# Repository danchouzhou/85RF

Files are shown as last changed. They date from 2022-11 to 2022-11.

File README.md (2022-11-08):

# 85RF
A 2.4G remote control made with ATtiny85
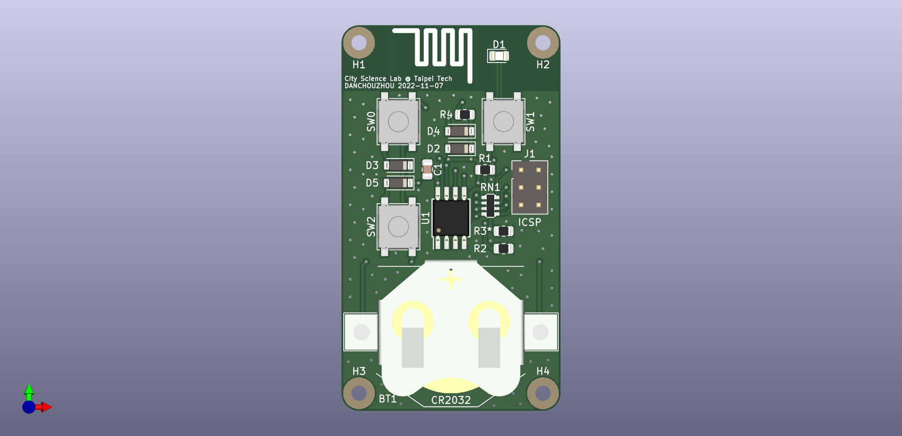
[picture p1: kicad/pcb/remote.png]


## Fetures
- ATtiny85 compatible with Arduino IDE
- nRF24L01+ / Si24R1 2.4G transceiver
- Zero quiescent current design
- Single CR2032 battery power, select one side to place the battery holder
- Onboard 6-pin AVR-ISP header for developing and re-programming

## Arduino IDE setup
### Board manager
Check out the [installation guide of ATTinyCore](https://github.com/SpenceKonde/ATTinyCore/blob/v2.0.0-devThis-is-the-head-submit-PRs-against-this/Installation.md) by Spence Konde (aka Dr. Azzy)

### Library
This project uses [RF24](https://github.com/nRF24/RF24) by 2bndy5, it's a famous library of nRF24L01. It is possible to install the library directly from the library manager.

## Datasheet
- [Atmel ATtiny25, ATtiny45, ATtiny85 Datasheet](https://ww1.microchip.com/downloads/en/DeviceDoc/Atmel-2586-AVR-8-bit-Microcontroller-ATtiny25-ATtiny45-ATtiny85_Datasheet.pdf)
- [nRF24L01P_PS_v1.0.pdf - Nordic Semiconductor](https://infocenter.nordicsemi.com/pdf/nRF24L01P_PS_v1.0.pdf)
- [Ai-thinker NF-03 Specification](https://docs.ai-thinker.com/_media/nf-03_specification_en.pdf)

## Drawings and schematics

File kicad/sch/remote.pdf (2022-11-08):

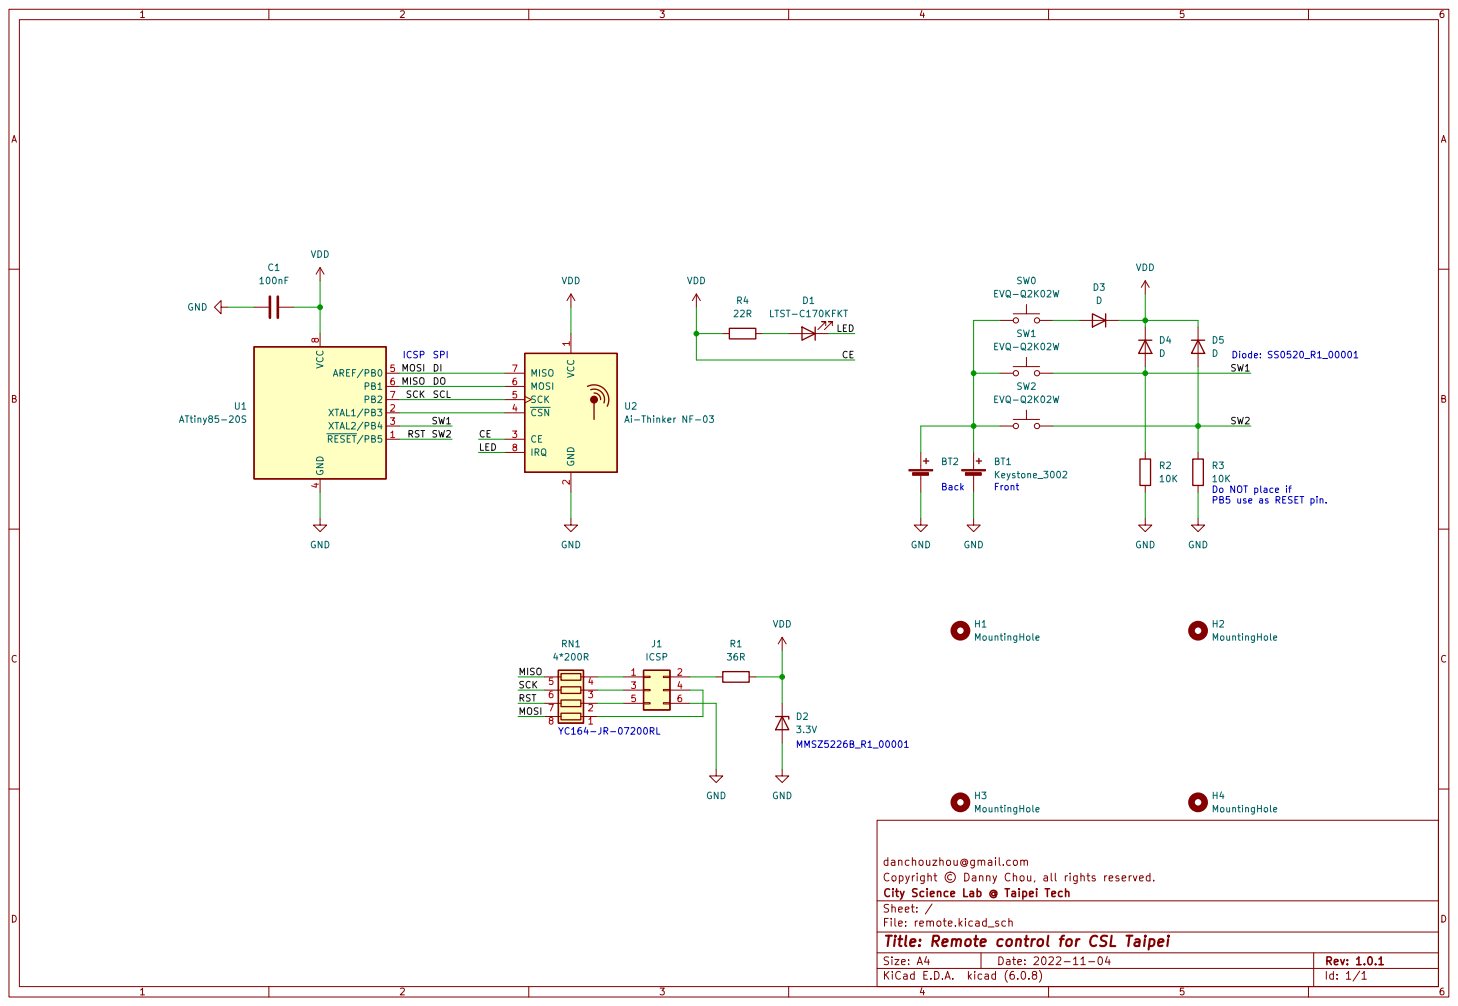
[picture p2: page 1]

2 CE 3 ~{CSN} 4 SCK 5 MOSI 6 MISO 7

danchouzhou@gmail.com
File: remote.kicad_sch Sheet: / City Science Lab @ Taipei Tech

Id: 1/1 Title: Remote control for CSL Taipei

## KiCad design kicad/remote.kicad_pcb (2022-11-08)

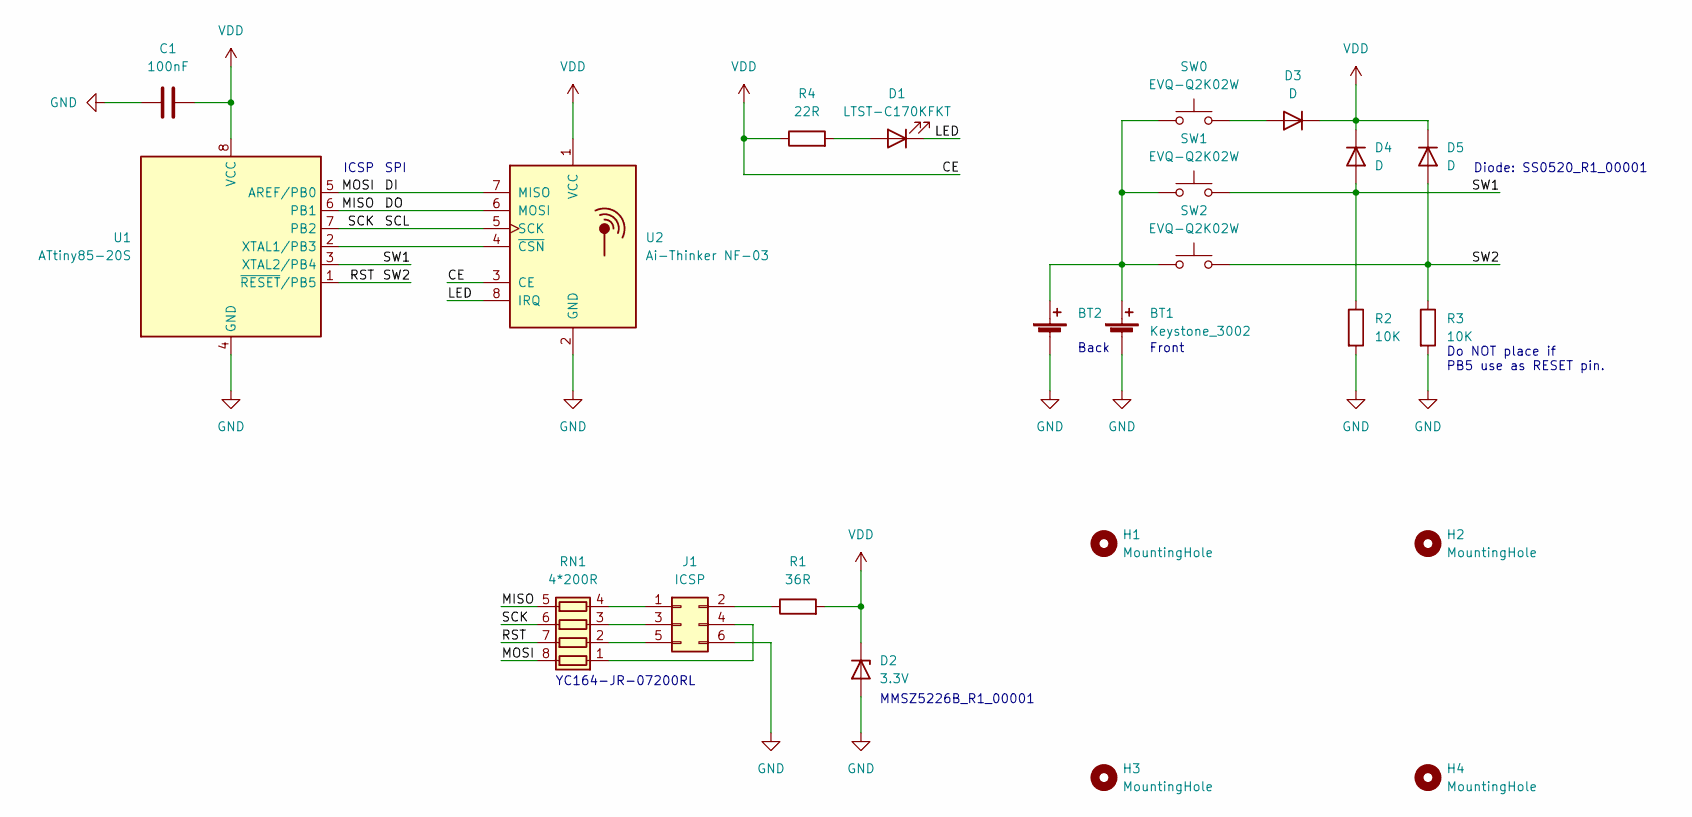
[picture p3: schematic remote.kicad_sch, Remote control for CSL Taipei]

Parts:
BT1: Keystone_3002; BatteryHolder_Keystone_3002_1x2032
BT2: BatteryHolder_Keystone_3002_1x2032
C1: 100nF; C_0805_2012Metric
D1: LTST-C170KFKT; LED_0805_2012Metric
D2: 3.3V; D_SOD-123
D3, D4, D5: D; D_SOD-123
H1, H2, H3, H4: MountingHole; MountingHole_2.2mm_M2
J1: ICSP; PinHeader_2x03_P2.54mm_Vertical
R1: 36R; R_0805_2012Metric
R2, R3: 10K; R_0805_2012Metric
R4: 22R; R_0805_2012Metric
RN1: 4*200R; R_Array_Convex_4x0603
SW0, SW1, SW2: EVQ-Q2K02W; SW_SPST_EVQP0
U1: ATtiny85-20S; SOIC-8W_5.3x5.3mm_P1.27mm
U2: Ai-Thinker NF-03; Ai-Thinker-NF-03

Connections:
/DI: RN1.8 (R1.2), U1.5 (AREF/PB0), U2.7 (MISO)
/DO: RN1.5 (R4.2), U1.6 (PB1), U2.6 (MOSI)
/LED: D1.1 (K), U2.8 (IRQ)
/RST: D5.2 (A), R3.1, RN1.7 (R2.2), SW2.2, U1.1 (~RESET/PB5); also elsewhere on the board
/SCK: RN1.6 (R3.2), U1.7 (PB2), U2.5 (SCK)
/SW1: D4.2 (A), R2.1, SW1.2, U1.3 (XTAL2/PB4)
GND: BT1.2 (-), BT2.2 (-), C1.1, D2.2 (A), J1.6, R2.2, R3.2, U1.4 (GND), U2.2 (GND); also elsewhere on the board
unnamed: BT1.1 (+), BT2.1 (+), SW0.1, SW1.1, SW2.1
unnamed: D1.2 (A), R4.2
unnamed: D3.2 (A), SW0.2
unnamed: J1.1, RN1.4 (R4.1)
unnamed: J1.2, R1.1
unnamed: J1.3, RN1.3 (R3.1)
unnamed: J1.4, RN1.1 (R1.1)
unnamed: J1.5, RN1.2 (R2.1)
unnamed: U1.2 (XTAL1/PB3), U2.4 (~CSN)
VDD: C1.2, D2.1 (K), D3.1 (K), D4.1 (K), D5.1 (K), R1.2, R4.1, U1.8 (VCC), U2.1 (VCC), U2.3 (CE)

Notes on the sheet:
Do NOT place if PB5 use as RESET pin.
ICSP
Front
Back
YC164-JR-07200RL
SPI
Diode: SS0520_R1_00001
MMSZ5226B_R1_00001

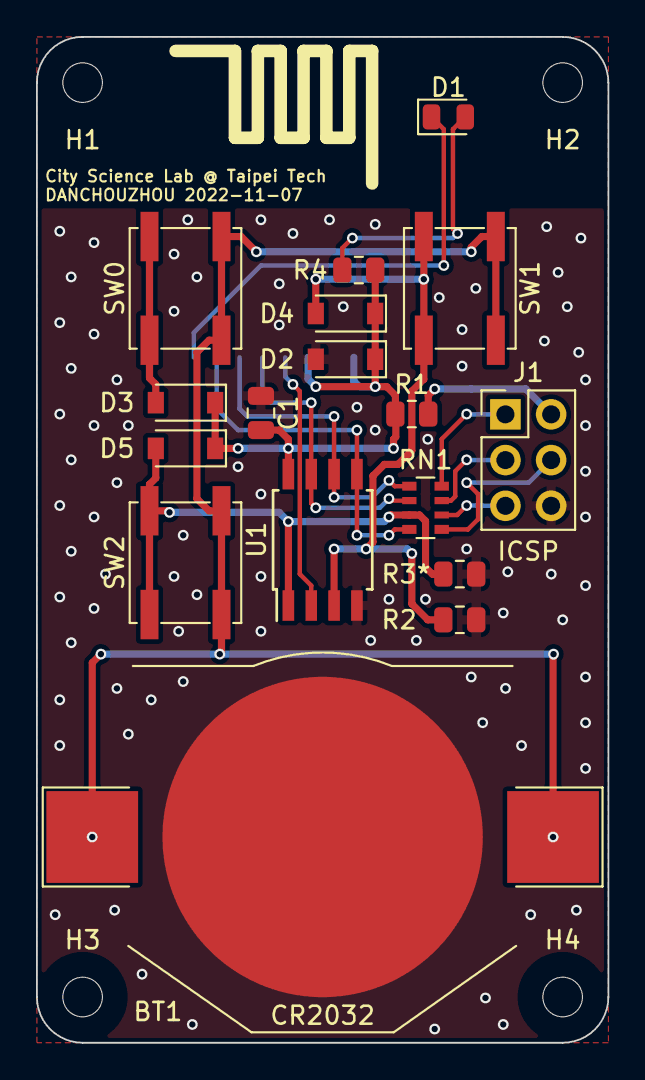
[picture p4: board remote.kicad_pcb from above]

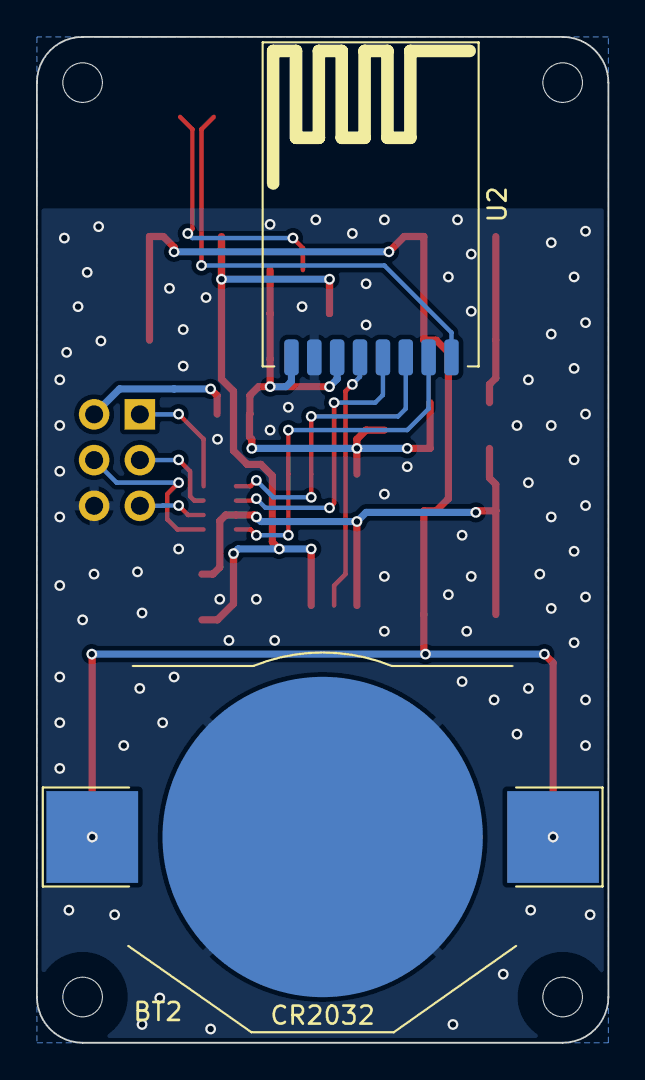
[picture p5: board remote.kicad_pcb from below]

Board: 2 copper layers, 31.8 x 55.9 mm, 23 parts (2 on the bottom side), 17 nets.

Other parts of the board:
R3*: 10K; R_0805_2012Metric

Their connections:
/RST: R3*.1; also elsewhere on the board
GND: R3*.2; also elsewhere on the board

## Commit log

2022-11-08 Add kicad files
    [remote-B_Cu.gbl, remote-B_Mask.gbs, remote-B_Silkscreen.gbo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]
2022-11-10 Add PCB 3D model

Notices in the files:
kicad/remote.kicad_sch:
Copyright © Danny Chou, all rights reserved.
